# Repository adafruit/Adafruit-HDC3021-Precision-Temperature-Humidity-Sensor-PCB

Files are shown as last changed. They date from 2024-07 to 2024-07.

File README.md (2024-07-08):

## Adafruit HDC3021 Precision Temperature Humidity Sensor - STEMMA QT / Qwiic PCB

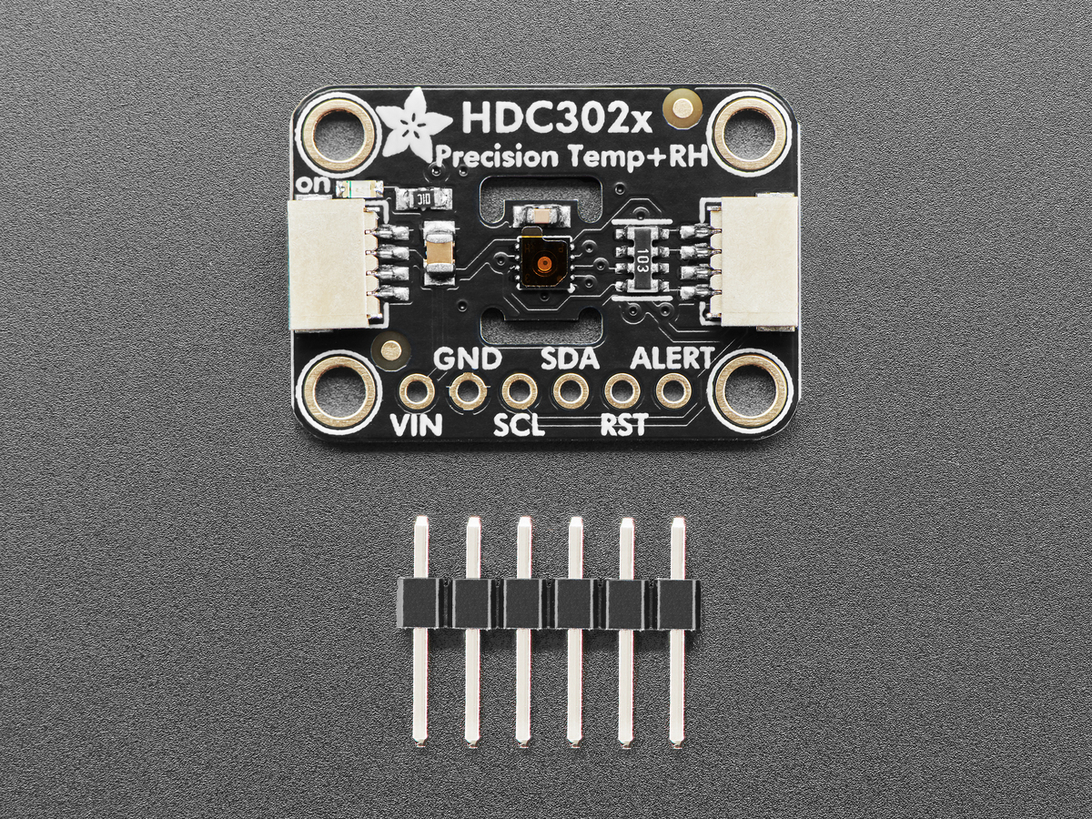
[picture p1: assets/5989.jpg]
<a href="http://www.adafruit.com/products/5989"><br/>
Click here to purchase one from the Adafruit shop</a>

PCB files for the Adafruit HDC3021 Precision Temperature Humidity Sensor - STEMMA QT / Qwiic. 

Format is EagleCAD schematic and board layout
* https://www.adafruit.com/product/5989

### Description

We stock a large number of Temperature/Humidity sensors, so you're probably wondering why another one? Well, this Adafruit HDC3021 Precision Temperature & Humidity Sensor breakout features the highest accuracy & precision one we've see so far! It has the TI HDC302x series chip with typical 0.5% accuracy for the RH sensor (with 0.19% long-term drift) and ±0.1°C typical accuracy for the temperature sensor. All at a very nice price.

This sensor has a true I2C interface for easy interfacing with only two wires (plus power and ground!). That makes it preferable to the janky DHT11/DHT22 sensors. The sensor is 5V safe, so you can use 1.8V to 5V power and logic levels without the need for shifters, so you can power and communicate with it using any microcontroller or microcomputer. With 4 selectable I2C addresses, you can have multiple sensors on one bus - unlike many other fixed-address T/RH sensors.

We've written a full-featured Arduino and CircuitPython/Python library, so whether you have an 8-bit microcontroller or a quad-core Raspberry Pi, you will be able to quickly get data from the sensor for your environmental monitoring needs. The library can setup the sensor rate/power, heater, alerts, offsets, and read data or NIST tracking ID.

Such a lovely chip - so we spun up a breakout board with the HDC3021 and some supporting circuitry such as pullup resistors and capacitors. To make things even easier, we've included SparkFun Qwiic compatible STEMMA QT connectors for the I2C bus so you don't even need to solder! QT Cable is not included, but we have a variety in the shop. 

If you prefer working on a breadboard, each order comes with one fully assembled and tested PCB breakout and a small piece of header. You'll need to solder the header onto the PCB, but it's fairly easy and takes only a few minutes even for a beginner. 

Please note: this sensor comes with a protective polyamide sticker on top, please remove before usage!

### License

Adafruit invests time and resources providing this open source design, please support Adafruit and open-source hardware by purchasing products from [Adafruit](https://www.adafruit.com)!

Designed by Limor Fried/Ladyada for Adafruit Industries.

Creative Commons Attribution/Share-Alike, all text above must be included in any redistribution. 
See license.txt for additional details.

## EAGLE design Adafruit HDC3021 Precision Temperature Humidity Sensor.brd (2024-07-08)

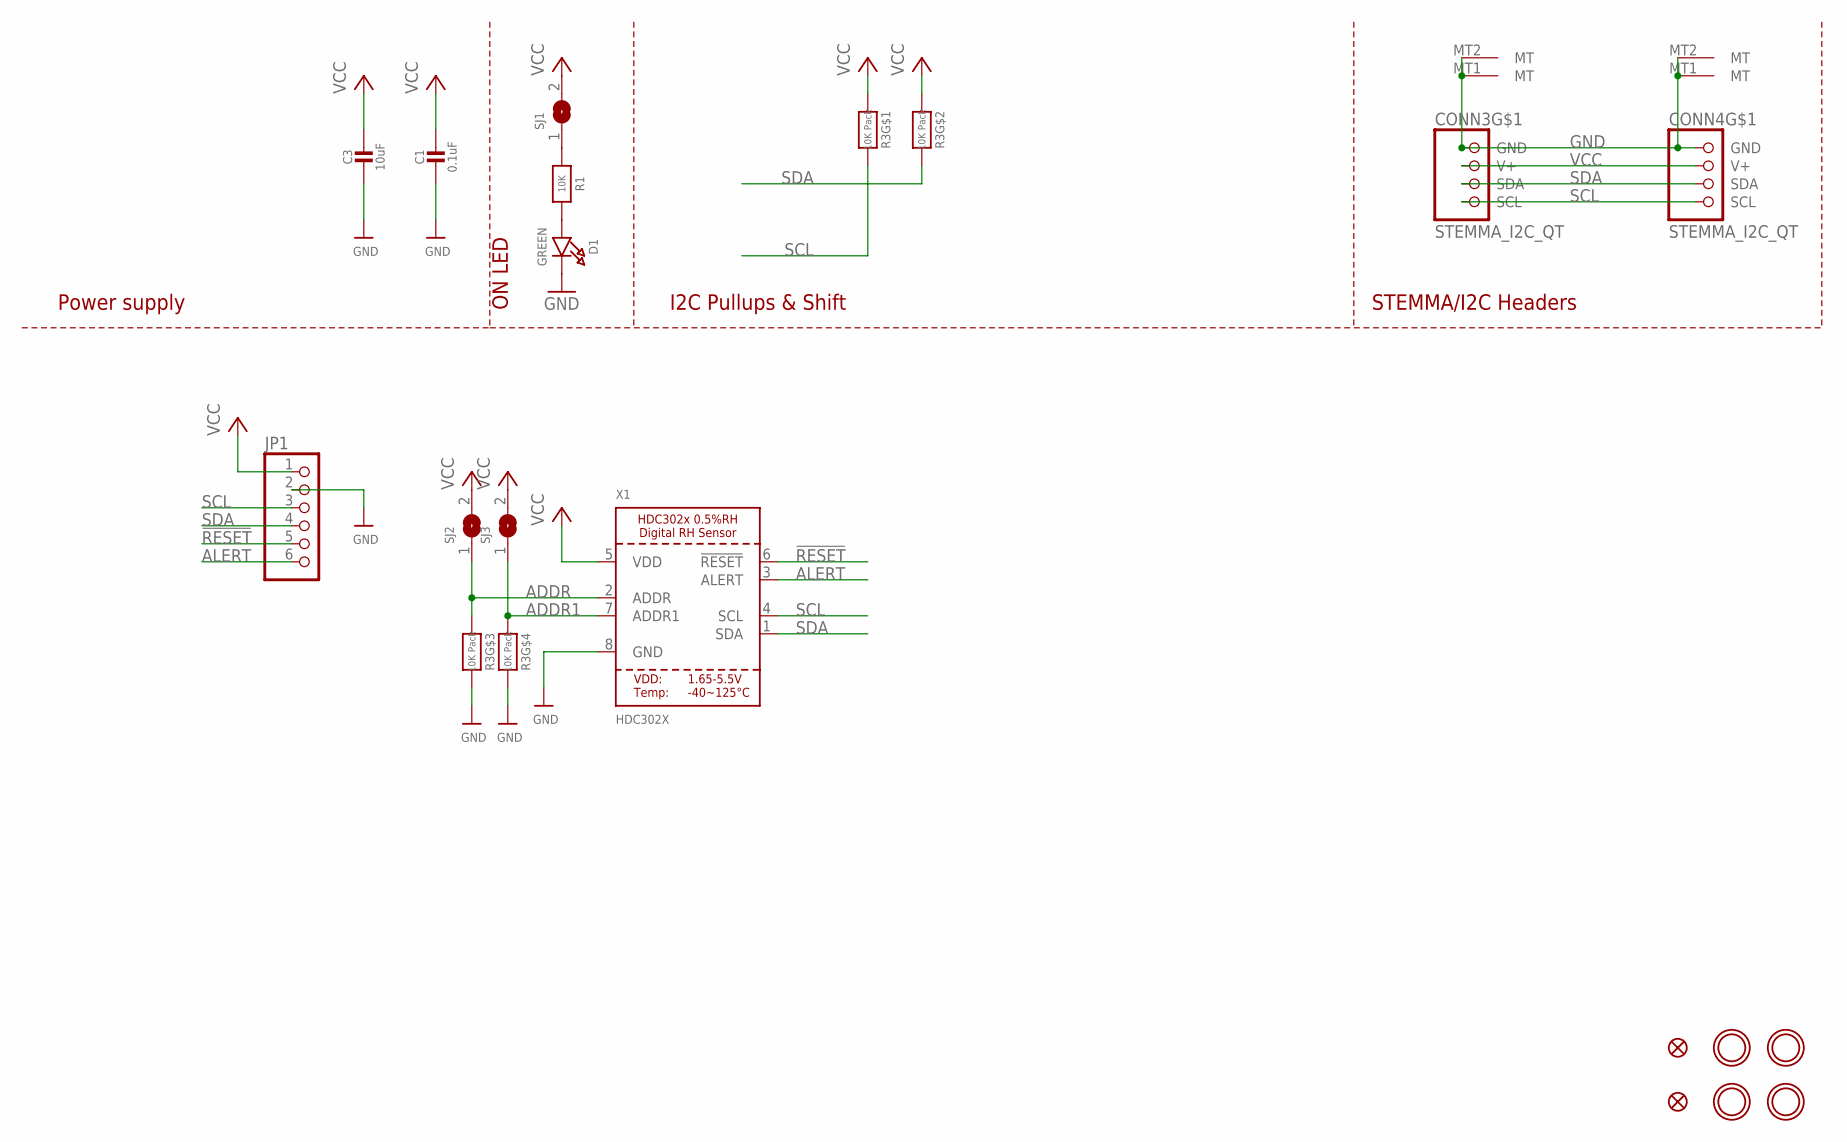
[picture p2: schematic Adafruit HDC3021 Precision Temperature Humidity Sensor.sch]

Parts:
C1: 0.1uF; 0603-NO
C3: 10uF; 0805-NO
CONN3, CONN4: STEMMA_I2C_QT; JST_SH4
D1: GREEN; CHIPLED_0603_NOOUTLINE
FID3, FID4: FIDUCIAL_1MM
JP1: HEADER-1X670MIL; 1X06_ROUND_70
R1: 10K; 0603-NO
R3: 10K Pack; RESPACK_4X0603
SJ1: SOLDERJUMPERCLOSED; SOLDERJUMPER_CLOSEDWIRE
SJ2, SJ3: SOLDERJUMPER; SOLDERJUMPER_ARROW_NOPASTE
U$1, U$17, U$19, U$21: MOUNTINGHOLE2.5; MOUNTINGHOLE_2.5_PLATED
X1: HDC302X; WSON8

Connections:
!RESET: JP1.5, X1.6 (!RESET)
ADDR: R3.3 (1), SJ2.1, X1.2 (ADDR)
ADDR1: R3.4 (1), SJ3.1, X1.7 (ADDR1)
ALERT: JP1.6, X1.3 (ALERT)
GND: C1.2, C3.2, CONN3.1 (GND), CONN3.MT1 (MT), CONN3.MT2 (MT), CONN4.1 (GND), CONN4.MT1 (MT), CONN4.MT2 (MT), D1.C, JP1.2, R3.5 (2), R3.6 (2), X1.8 (GND)
unnamed: D1.A, R1.2
unnamed: R1.1, SJ1.1
SCL: CONN3.4 (SCL), CONN4.4 (SCL), JP1.3, R3.8 (2), X1.4 (SCL)
SDA: CONN3.3 (SDA), CONN4.3 (SDA), JP1.4, R3.7 (2), X1.1 (SDA)
VCC: C1.1, C3.1, CONN3.2 (V+), CONN4.2 (V+), JP1.1, R3.1, R3.2 (1), SJ1.2, SJ2.2, SJ3.2, X1.5 (VDD)

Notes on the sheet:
I2C Pullups & Shift
STEMMA/I2C Headers
ON LED
Power supply

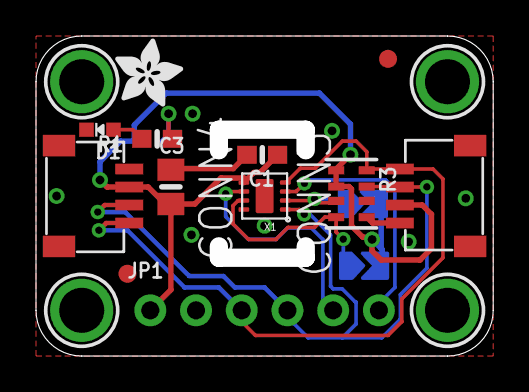
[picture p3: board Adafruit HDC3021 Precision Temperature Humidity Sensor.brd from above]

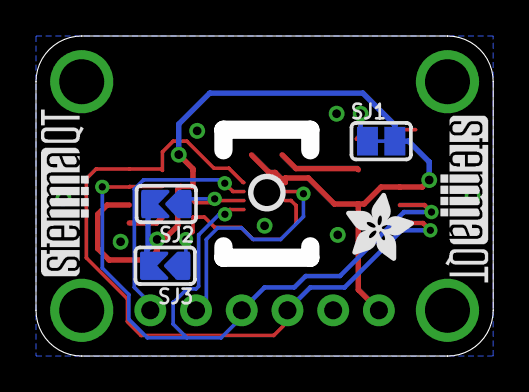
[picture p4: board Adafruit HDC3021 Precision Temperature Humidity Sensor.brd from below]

Board: 2 copper layers, 25.4 x 17.8 mm, 39 parts (14 on the bottom side), 10 nets.

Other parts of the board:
PLABEL0: PLABEL0
PLABEL1: PLABEL1
PLABEL2: PLABEL2
PLABEL3: PLABEL3
PLABEL4: PLABEL4
PLABEL5: PLABEL5
PLABEL6: PLABEL6
PLABEL7: PLABEL7
PLABEL8: PLABEL8
PLABEL9: PLABEL9
PLABEL10: PLABEL10
PLABEL11: PLABEL11
PLABEL12: PLABEL12
PLABEL13: PLABEL13
PLABEL14: PLABEL14
PLABEL15: PLABEL15
U$7, U$22: ADAFRUIT_3.5MM
U$25: PCBFEAT-REV-040
U$30, U$31: STEMMAQT

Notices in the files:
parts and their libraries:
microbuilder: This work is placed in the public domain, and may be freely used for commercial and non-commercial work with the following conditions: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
